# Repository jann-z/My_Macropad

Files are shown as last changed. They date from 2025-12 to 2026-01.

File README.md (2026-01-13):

# My Macropad

Welcome to my Macropad project! 
This repository contains all the design files for the case, the PCB, and the firmware necessary to build this custom keypad.

## Project Overview

This project is a fully custom-designed macropad built around the Seeed XIAO RP2040 microcontroller.
Designed as part of the Hack Club submission, the goal was to create a functional, budget-friendly input device.

The device features are 6 mechanical switches for a tactile typing experience.
The PCB was created using KiCad, keeping the layout clean and efficient on a 2-layers.

Running on QMK firmware, the pad is fully programmable, allowing users to customize keymaps for gaming, coding shortcuts, or media control.
It serves as both a practical tool and a showcase of custom hardware design.

The case is version 2 because without the "bump" (inspired by Google Pixel camera-bump), the rotary encoder wouldn't fit.

## Design & Visuals

Per the submission requirements, here are the different views of the project:

### 1. The Assembled Macropad (Render)
A 3D render of the complete assembly (Case + PCB):
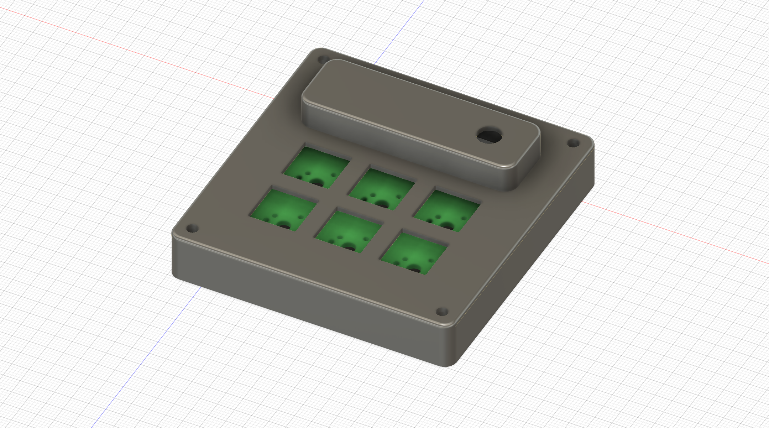
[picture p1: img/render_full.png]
Full Assembly


### 2. Case Design
The 3D printed Case and Top:
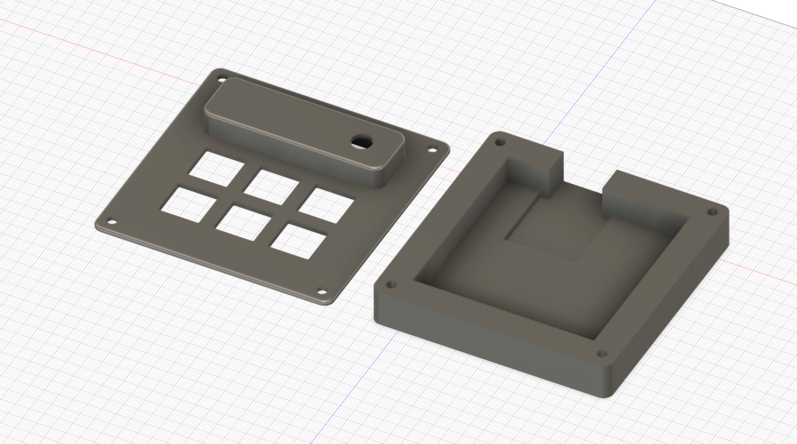
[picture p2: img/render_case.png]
Case Assembly

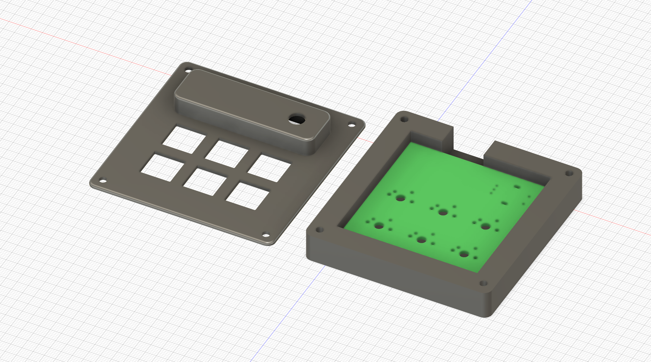
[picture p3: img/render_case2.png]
Case Assembly 2


### 3. PCB Layout
A view of the PCB routing:
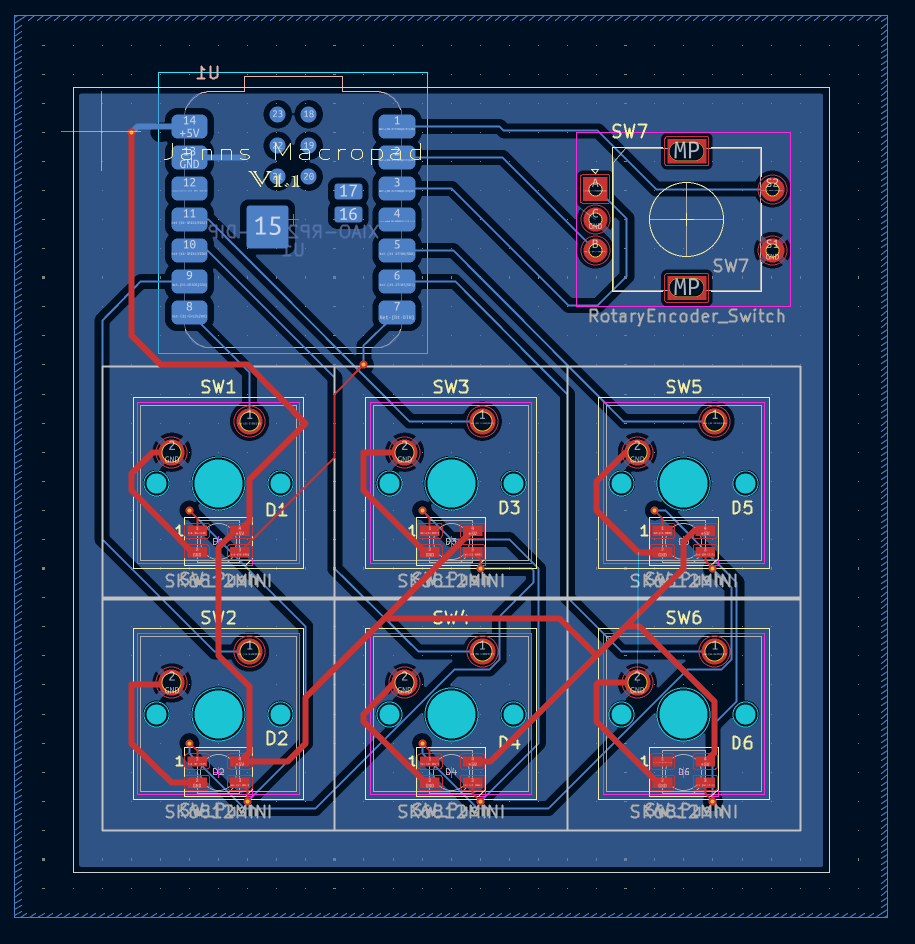
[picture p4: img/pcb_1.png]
PCB Layout1

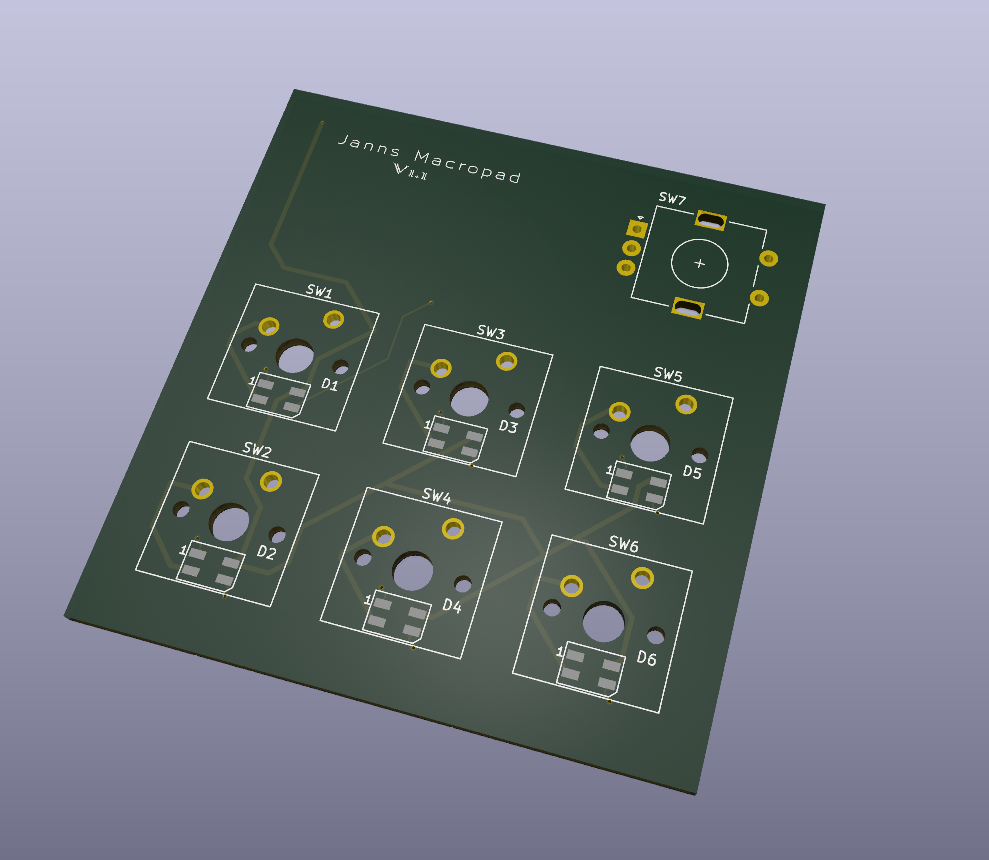
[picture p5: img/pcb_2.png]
PCB Layout2

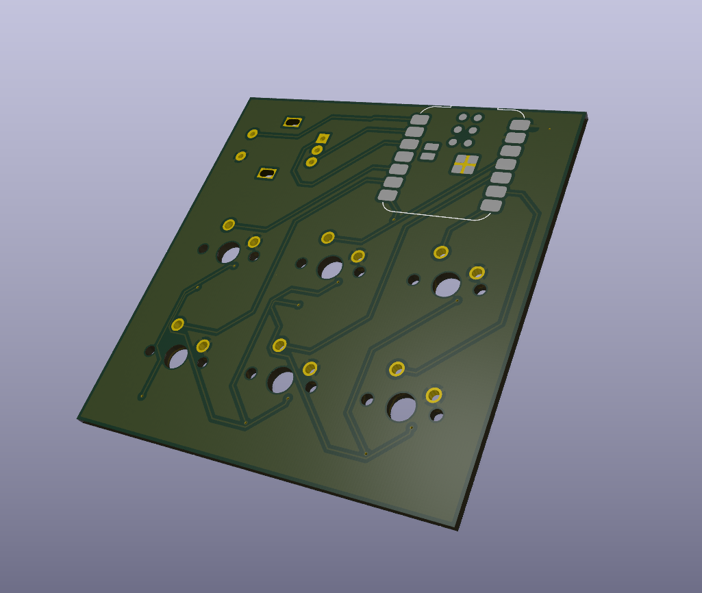
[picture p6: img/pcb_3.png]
PCB Layout3


### 4. Schematic
The electronic schematic for the device:
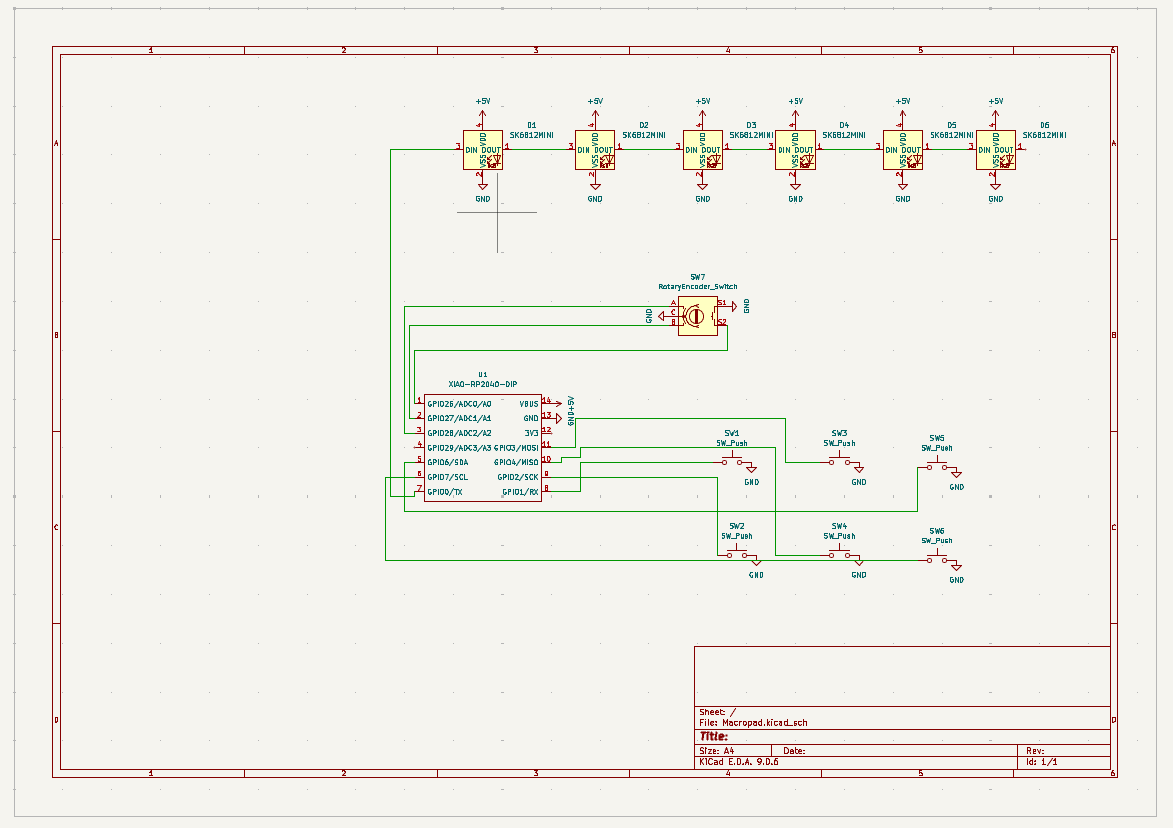
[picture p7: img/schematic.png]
Schematic


---

## Default keymap

* **SW1** Copy
* **SW2** Undo
* **SW3** Clipboard (Paste)
* **SW4** Explorer
* **SW5** Cut
* **SW6** Taskmanager

### Rotary Encoder (EC11)

Modes are changet by pressing the switch of the Encoder (SW7):

* **Mode 1** Volume
* **Mode 2** RGB Brightness
* **Mode 3** RGB Pattern

## Bill of Materials (BOM)

Here are the parts required to build this macropad:

| Component | Quantity | Description / Notes |
| :--- | :---: | :--- |
| Seeed XIAO RP2040 | 1 | The main microcontroller |
| Cherry MX Switches | 6 | (or compatible clones) |
| Keycaps | 6 | Compatible with chosen switches |
| SK6812 MINI-E LED | 6 | (or fitting neopixel-leds) |
| EC11 Rotary encoder | 1 | For Volume, Brightness, ect. |
| 3D Print Filament | - | PLA or PETG for the case |
| Screws | 4 | M3x16mm for assembly (Thread trough Plastic) |

---

## Features

* **MCU:** Seeed XIAO RP2040
* **Firmware:** QMK
* **Connectivity:** USB-C

## License
This project is open source.

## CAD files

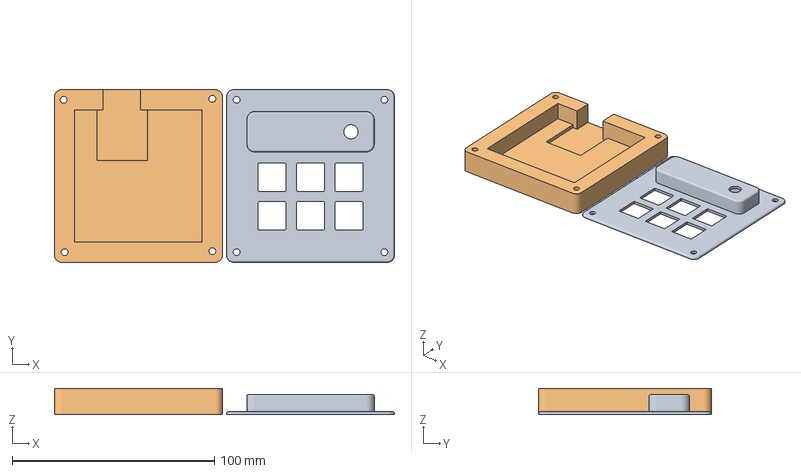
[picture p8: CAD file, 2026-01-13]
CAD/Janns_Macropad_3DP_V2.3mf
168.0 x 85.3 x 13.0 mm
Janns_Macropad_top_V2.step
Janns_Macropad_Base.step

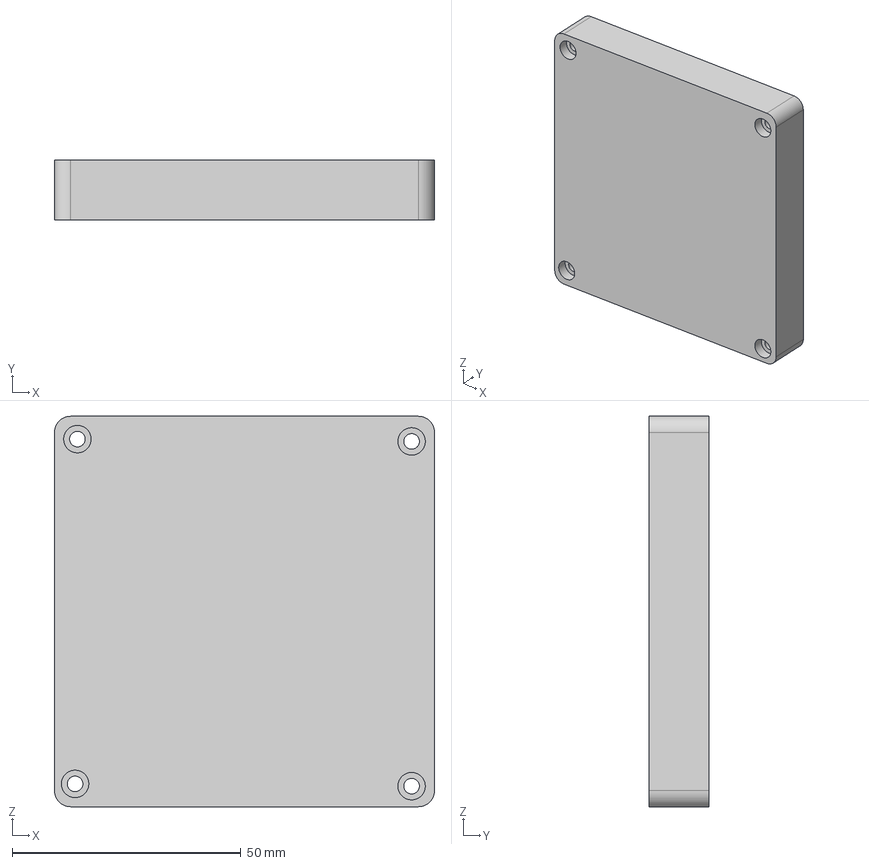
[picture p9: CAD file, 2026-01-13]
CAD/Case_AIO_V2.step
83.0 x 13.0 x 85.3 mm

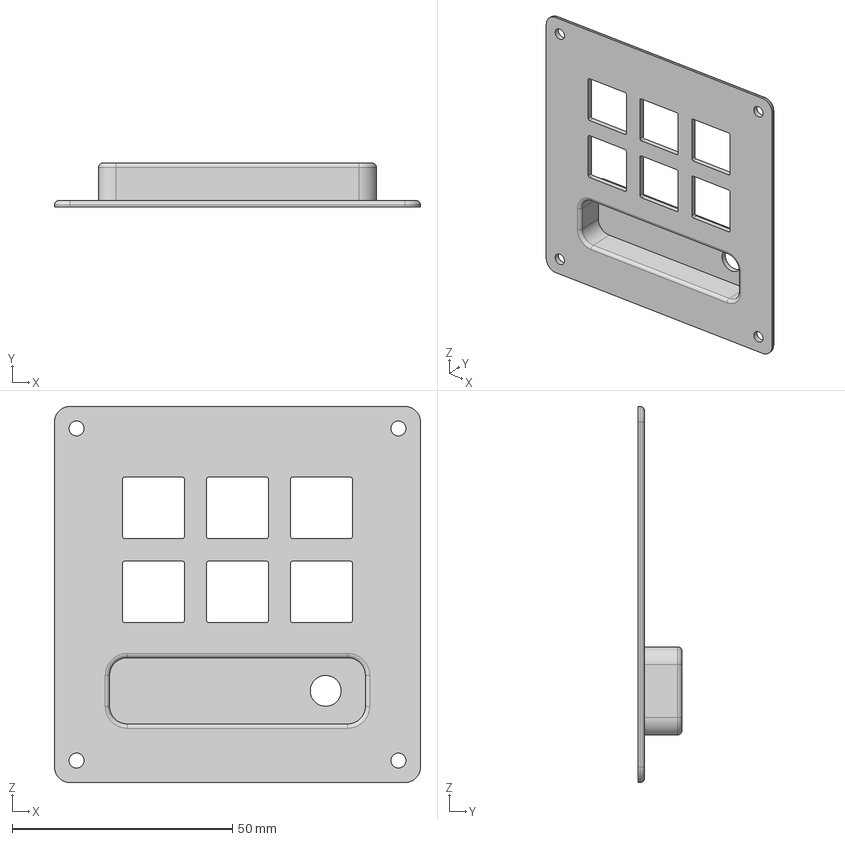
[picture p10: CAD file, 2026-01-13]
CAD/Janns_Macropad_top_V2.step
83.0 x 10.0 x 85.3 mm

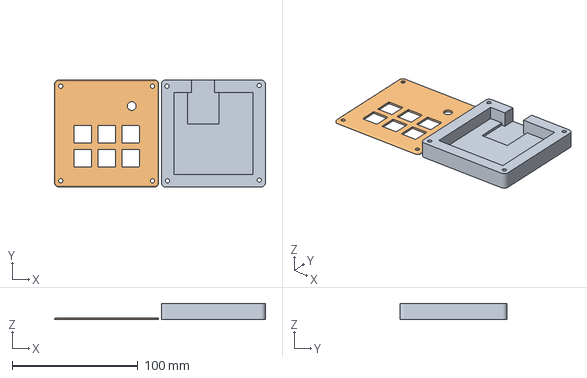
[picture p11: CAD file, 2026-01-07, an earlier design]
CAD/old/Janns_Macropad_3Dp.3mf
168.0 x 85.3 x 13.0 mm
Janns_Macropad_Base.step
Janns Macropad top.stl

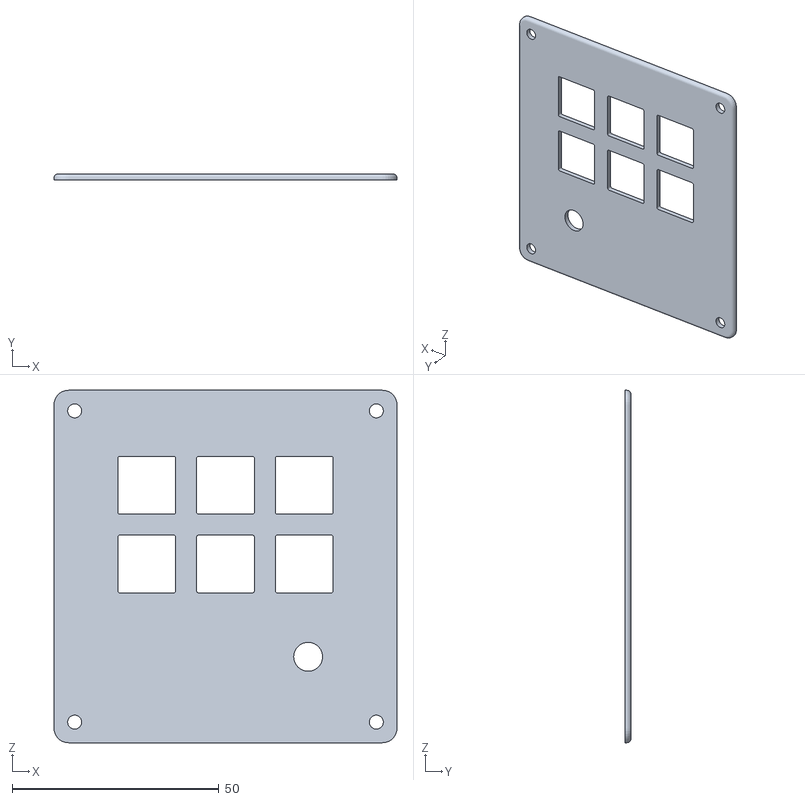
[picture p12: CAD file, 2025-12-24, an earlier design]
CAD/old/Janns Macropad top.stl
83.0 x 1.50 x 85.3

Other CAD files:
CAD/Janns_Macropad_Base.step

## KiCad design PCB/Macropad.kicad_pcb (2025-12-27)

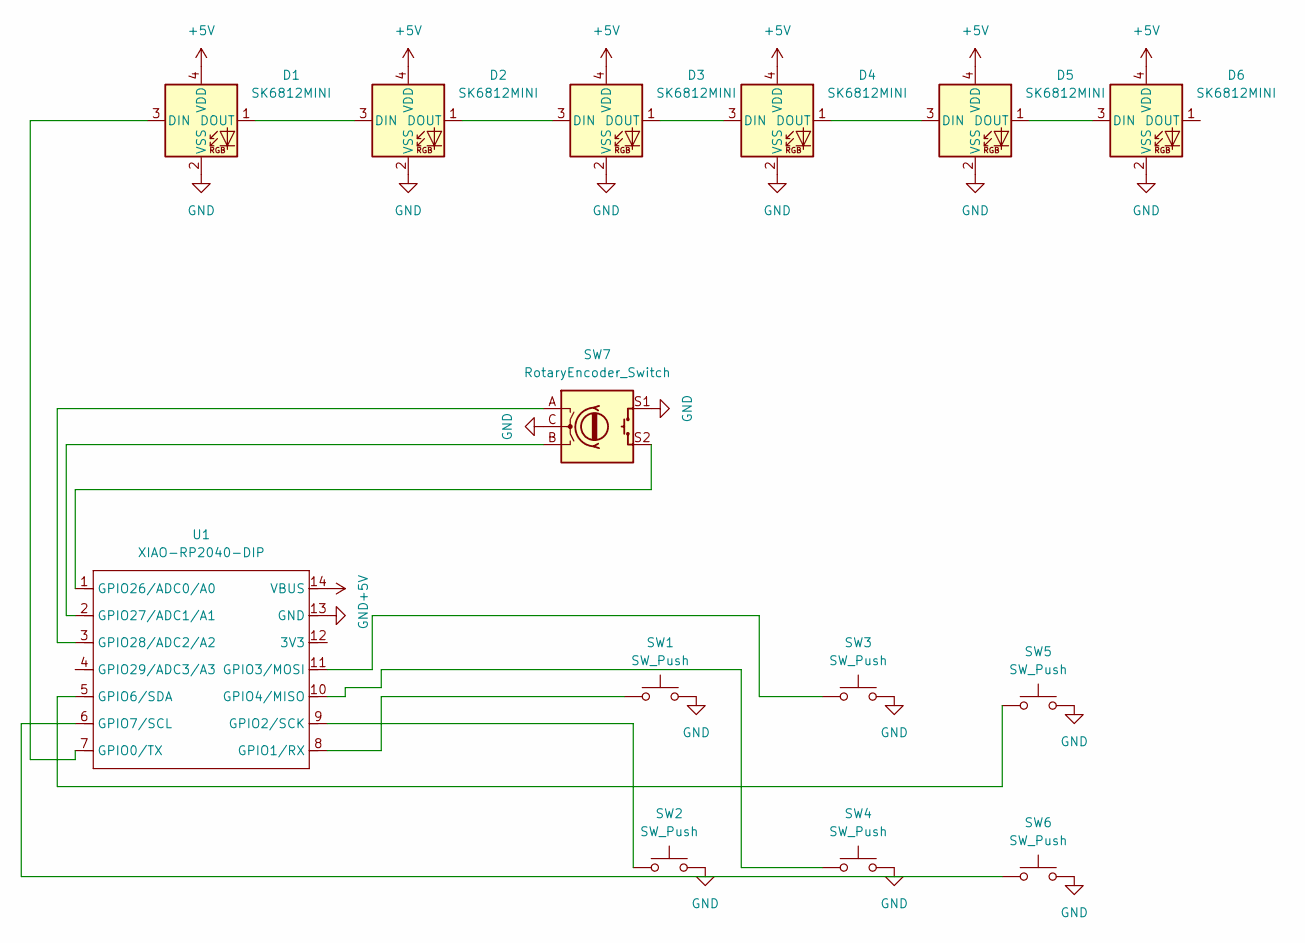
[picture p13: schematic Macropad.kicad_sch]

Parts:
D1, D2, D3, D4, D5, D6: SK6812MINI; LED_SK6812MINI_PLCC4_3.5x3.5mm_P1.75mm
SW1, SW2, SW3, SW4, SW5, SW6: SW_Push; SW_Cherry_MX_1.00u_PCB
SW7: RotaryEncoder_Switch; RotaryEncoder_Alps_EC11E-Switch_Vertical_H20mm
U1: XIAO-RP2040-DIP; MCU_Seeed_ESP32C3

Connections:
+5V: D1.4 (VDD), D2.4 (VDD), D3.4 (VDD), D4.4 (VDD), D5.4 (VDD), D6.4 (VDD), U1.14 (VBUS)
GND: D1.2 (VSS), D2.2 (VSS), D3.2 (VSS), D4.2 (VSS), D5.2 (VSS), D6.2 (VSS), SW1.2, SW2.2, SW3.2, SW4.2, SW5.2, SW6.2, SW7.C, SW7.S1, U1.13 (GND)
unnamed: D1.3 (DIN), U1.7 (GPIO0/TX)
unnamed: D1.1 (DOUT), D2.3 (DIN)
unnamed: D2.1 (DOUT), D3.3 (DIN)
unnamed: D3.1 (DOUT), D4.3 (DIN)
unnamed: D4.1 (DOUT), D5.3 (DIN)
unnamed: D5.1 (DOUT), D6.3 (DIN)
unnamed: SW1.1, U1.8 (GPIO1/RX)
unnamed: SW2.1, U1.9 (GPIO2/SCK)
unnamed: SW3.1, U1.11 (GPIO3/MOSI)
unnamed: SW4.1, U1.10 (GPIO4/MISO)
unnamed: SW5.1, U1.5 (GPIO6/SDA)
unnamed: SW6.1, U1.6 (GPIO7/SCL)
unnamed: SW7.S2, U1.1 (GPIO26/ADC0/A0)
unnamed: SW7.B, U1.2 (GPIO27/ADC1/A1)
unnamed: SW7.A, U1.3 (GPIO28/ADC2/A2)

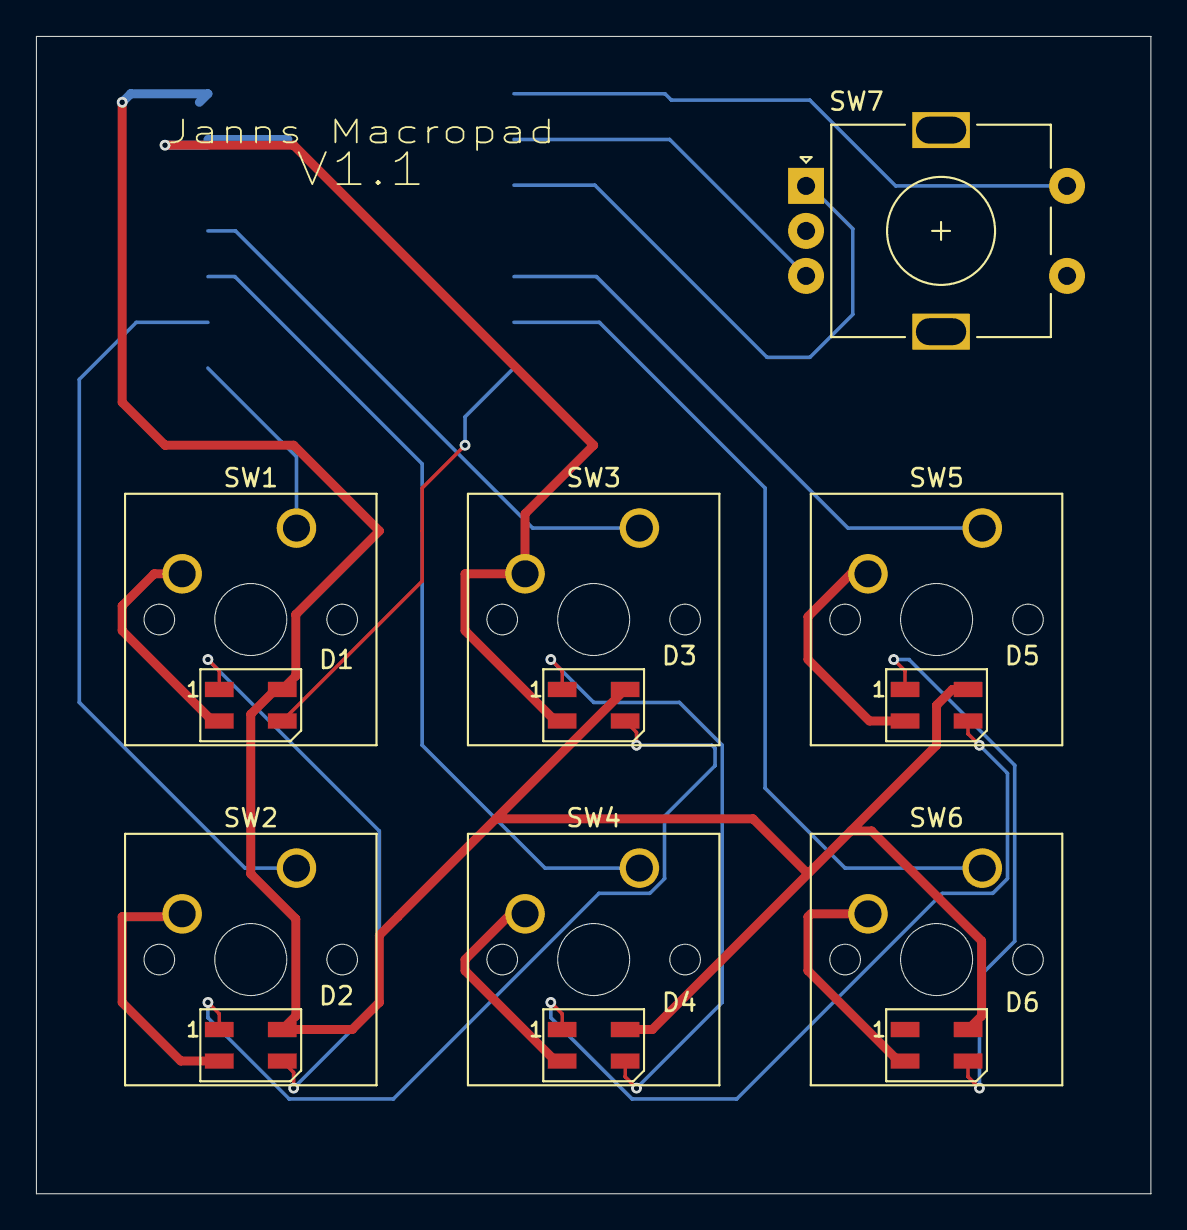
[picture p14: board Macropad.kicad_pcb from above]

Board: 2 copper layers, 61.9 x 64.3 mm, 14 parts (1 on the bottom side), 17 nets.

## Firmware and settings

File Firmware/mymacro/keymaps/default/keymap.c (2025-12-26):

#include QMK_KEYBOARD_H

// 1. Definitionen für unsere Logik
enum custom_keycodes {
    MODE_SW = SAFE_RANGE
};

int encoder_mode = 0; // Startet bei Modus 0 (Lautstärke)

// 2. Deine Tastenbelegung
const uint16_t PROGMEM keymaps[][MATRIX_ROWS][MATRIX_COLS] = {
    [0] = LAYOUT(
        // Zeile 1: Copy, Win+V (Clipboard), Cut
        C(KC_C),    G(KC_V),    C(KC_X),   
        
        // Zeile 2: Undo, Win+E (Explorer), Task Manager
        C(KC_Z),    G(KC_E),    C(S(KC_ESC)),   

        // Encoder Klick -> Wechselt jetzt die Modi durch
        MODE_SW
    )
};

// 3. Logik für den Button-Druck (Modus wechseln + Farbe als Feedback)
bool process_record_user(uint16_t keycode, keyrecord_t *record) {
    switch (keycode) {
        case MODE_SW:
            if (record->event.pressed) {
                // Modus hochzählen: 0 -> 1 -> 2 -> 0 ...
                encoder_mode = (encoder_mode + 1) % 3;
                
                // Visuelles Feedback
                if (encoder_mode == 0) {
                    // Modus 0: Lautstärke -> Weiß
                    rgblight_sethsv_noeeprom(HSV_WHITE); 
                    rgblight_mode_noeeprom(RGBLIGHT_MODE_STATIC_LIGHT);
                } 
                else if (encoder_mode == 1) {
                    // Modus 1: RGB Effekt -> Blau
                    rgblight_sethsv_noeeprom(HSV_BLUE);
                    rgblight_mode_noeeprom(RGBLIGHT_MODE_BREATHING);
                } 
                else if (encoder_mode == 2) {
                    // Modus 2: Helligkeit -> Rot
                    rgblight_sethsv_noeeprom(HSV_RED);
                    // Hier der Fix: STATIC_LIGHT statt BLINKING
                    rgblight_mode_noeeprom(RGBLIGHT_MODE_STATIC_LIGHT); 
                }
            }
            return false; // Wir haben den Keycode behandelt
    }
    return true; // Alle anderen Tasten normal verarbeiten
}

// 4. Logik für das Drehen (abhängig vom Modus)
bool encoder_update_user(uint8_t index, bool clockwise) {
    if (index == 0) { 
        switch (encoder_mode) {
            case 0: // Modus 0: Lautstärke
                if (clockwise) {
                    tap_code(KC_VOLU);
                } else {
                    tap_code(KC_VOLD);
                }
                break;

            case 1: // Modus 1: RGB Animation wechseln
                if (clockwise) {
                    rgblight_step(); // Nächster Effekt
                } else {
                    rgblight_step_reverse(); // Vorheriger Effekt
                }
                break;

            case 2: // Modus 2: Helligkeit
                if (clockwise) {
                    rgblight_increase_val(); // Heller
                } else {
                    rgblight_decrease_val(); // Dunkler
                }
                break;
        }
    }
    return false;
}

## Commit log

2025-12-24 Added all Macropad files
    [Janns Macropad top.stl, Janns Macropad.step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]
2025-12-26 Updated Filesystem
    For Hackclub Submission Guidelines
    [Macropad.kicad_pcb, Macropad.kicad_sch, Macropad_Case_AIO.step]
2025-12-26 Added README
    Added detailed project description, visuals, BOM, features, and license information.
2025-12-26 Better README
    Updated the description of the case design section.
2025-12-27 Document Rotary Encoder modes in README
    Added section about Rotary Encoder modes to README.
2025-12-27 Fix typo in Rotary Encoder modes description
    Corrected a typo in the modes description for the Rotary Encoder.
2025-12-27 Add second case assembly image to README
2025-12-27 Fixed Faital Error with GND plate
    [Macropad.kicad_pcb]
2025-12-27 Fixed Faital Error with PCB Gnd Plate
2026-01-07 Added the final gerber files I sent to JLCPCB
    [Macropad-B_Cu.gbr, Macropad-B_Mask.gbr, Macropad-B_Paste.gbr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]
2026-01-07 Added a printable 3mf File
    [Janns_Macropad_3Dp.3mf]
2026-01-13 New Version of top case
    (inspired by Google Pixel camera-bump)
    [Case_AIO_V2.step, Janns Macropad top.stl, Janns_Macropad_3Dp.3mf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]
2026-01-13 added a 3mf for esyer printing
    [Janns_Macropad_3DP_V2.3mf]
2026-01-13 Clarify case version 2 design rationale
    Added explanation for case version 2 regarding rotary encoder fit.
